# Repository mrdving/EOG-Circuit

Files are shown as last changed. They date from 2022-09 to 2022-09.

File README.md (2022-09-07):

# EOG-Circuit
An EOG circuit that gets the signal from the eye movement, and uses the output to control a game

EOG-TestDrive is the Unity Game. Created with Unity Engine version 2019.4.17f1
In the game, run Game scene and press space bar to begin, 'a' to move left, 'd' to move right

Keyboard_test.ino is the Script that runs in Arduino. Beware that only certain modules support the <Keyboard> package, such as Leonardo, but not Uno

CircuitDiagram Provides information on the components and connections

PCB contains KiCad file open with KiCad

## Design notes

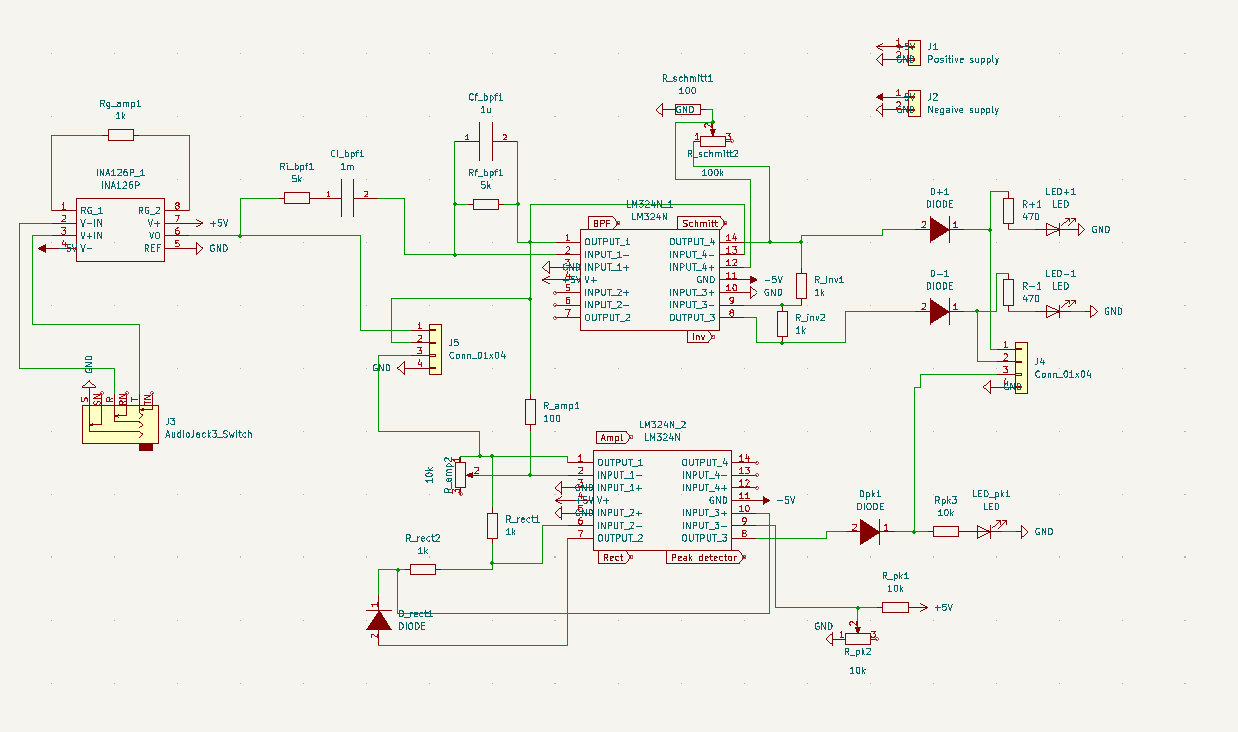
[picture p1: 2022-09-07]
CircuitDiagram.png

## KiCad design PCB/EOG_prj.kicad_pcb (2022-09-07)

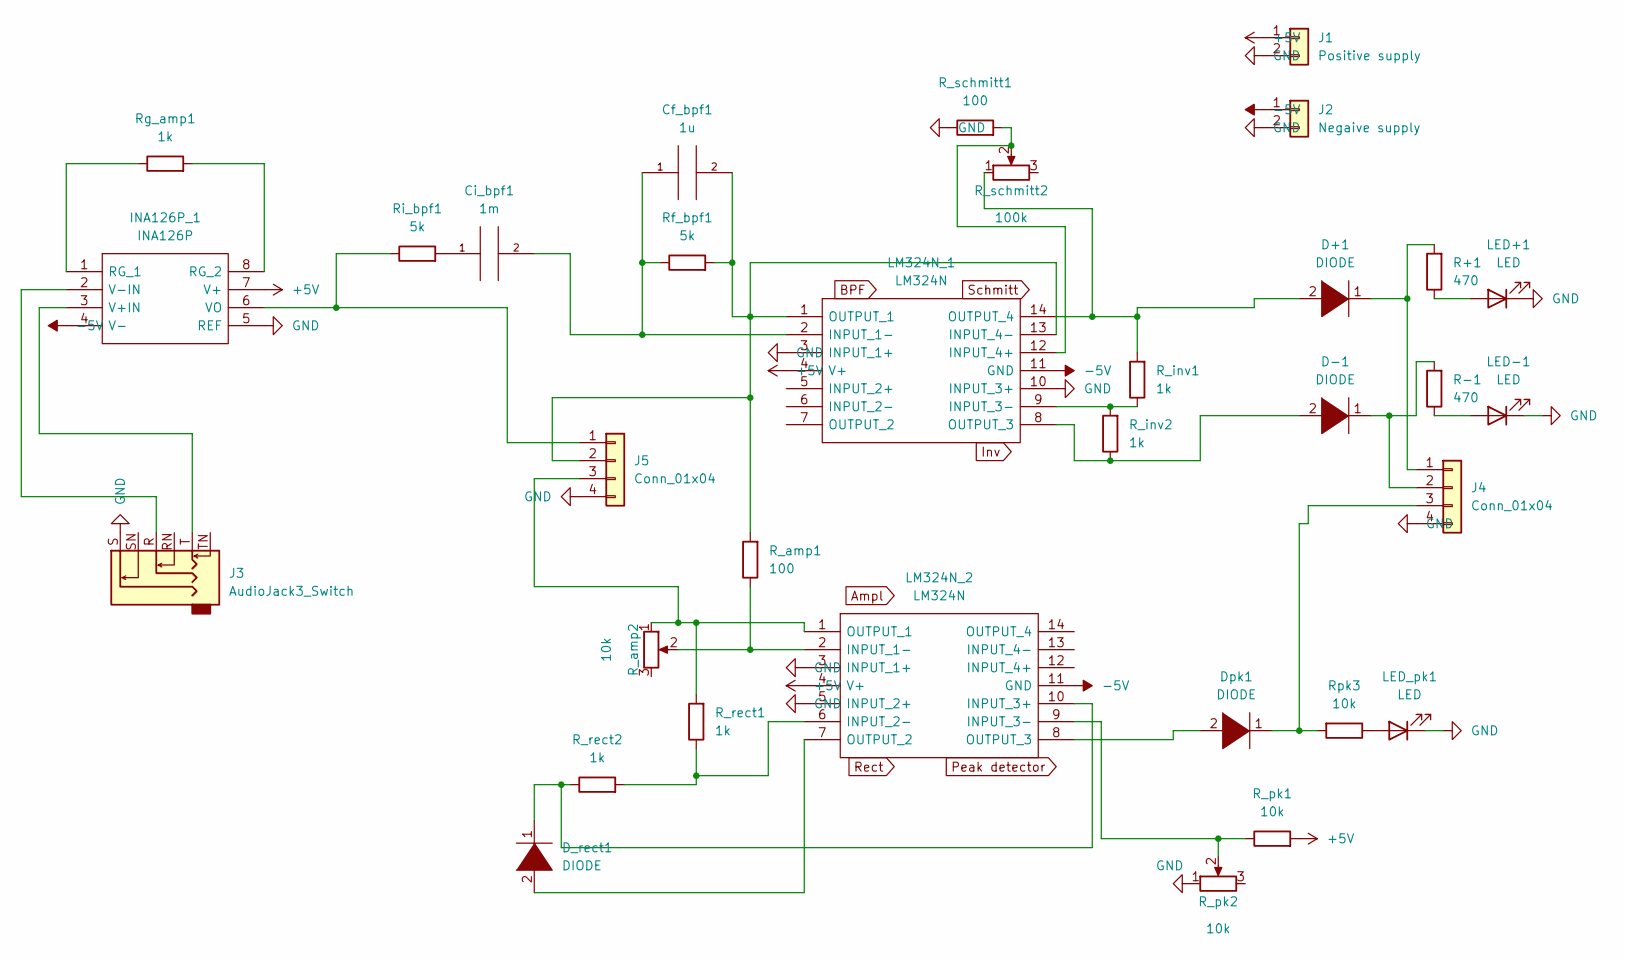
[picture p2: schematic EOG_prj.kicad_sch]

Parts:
Cf_bpf1: 1u; C_Radial_D5.0mm_H5.0mm_P2.00mm
Ci_bpf1: 1m; C_Radial_D12.5mm_H20.0mm_P5.00mm
D+1: DIODE; D_A-405_P10.16mm_Horizontal
D-1: DIODE; D_A-405_P10.16mm_Horizontal
D_rect1: DIODE; D_A-405_P10.16mm_Horizontal
Dpk1: DIODE; D_A-405_P10.16mm_Horizontal
INA126P_1: INA126P; DIP794W53P254L959H508Q8N; Manufacturer_Part_Number INA126P; Mouser Part Number 595-INA126P
J1: Positive supply; SolderWire-0.1sqmm_1x02_P3.6mm_D0.4mm_OD1mm
J2: Negaive supply; SolderWire-0.1sqmm_1x02_P3.6mm_D0.4mm_OD1mm
J3: AudioJack3_Switch; Jack_3.5mm_CUI_SJ1-3525N_Horizontal
J4, J5: Conn_01x04; SolderWire-0.1sqmm_1x04_P3.6mm_D0.4mm_OD1mm
LED+1: LED; LED_D3.0mm_Horizontal_O3.81mm_Z6.0mm
LED-1: LED; LED_D3.0mm_Horizontal_O3.81mm_Z6.0mm
LED_pk1: LED; LED_D3.0mm_Horizontal_O3.81mm_Z6.0mm
LM324N_1, LM324N_2: LM324N; DIP794W56P254L1905H533Q14N; Manufacturer_Part_Number LM324N; Mouser Part Number 595-LM324N
R+1: 470; R_Axial_DIN0207_L6.3mm_D2.5mm_P10.16mm_Horizontal
R-1: 470; R_Axial_DIN0207_L6.3mm_D2.5mm_P10.16mm_Horizontal
R_amp1: 100; R_Axial_DIN0207_L6.3mm_D2.5mm_P10.16mm_Horizontal
R_amp2: 10k; Potentiometer_Bourns_3339W_Horizontal
R_inv1, R_inv2: 1k; R_Axial_DIN0207_L6.3mm_D2.5mm_P10.16mm_Horizontal
R_pk1: 10k; R_Axial_DIN0207_L6.3mm_D2.5mm_P10.16mm_Horizontal
R_pk2: 10k; Potentiometer_Bourns_3339W_Horizontal
R_rect1, R_rect2: 1k; R_Axial_DIN0207_L6.3mm_D2.5mm_P10.16mm_Horizontal
R_schmitt1: 100; R_Axial_DIN0207_L6.3mm_D2.5mm_P10.16mm_Horizontal
R_schmitt2: 100k; Potentiometer_Bourns_3339W_Horizontal
Rf_bpf1: 5k; R_Axial_DIN0207_L6.3mm_D2.5mm_P10.16mm_Horizontal
Rg_amp1: 1k; R_Axial_DIN0207_L6.3mm_D2.5mm_P10.16mm_Horizontal
Ri_bpf1: 5k; R_Axial_DIN0207_L6.3mm_D2.5mm_P10.16mm_Horizontal
Rpk3: 10k; R_Axial_DIN0207_L6.3mm_D2.5mm_P10.16mm_Horizontal

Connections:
+5V: INA126P_1.7 (V+), J1.1, LM324N_1.4 (V+), LM324N_2.4 (V+), R_pk1.2
-5V: INA126P_1.4 (V-), J2.1, LM324N_1.11 (GND), LM324N_2.11 (GND)
GND: INA126P_1.5 (REF), J1.2, J2.2, J3.S, J4.4, J5.4, LED+1.1 (K), LED-1.1 (K), LED_pk1.1 (K), LM324N_1.3 (INPUT_1+), LM324N_1.10 (INPUT_3+), LM324N_2.3 (INPUT_1+), LM324N_2.5 (INPUT_2+), R_pk2.1, R_schmitt1.1
unnamed: Cf_bpf1.1, Ci_bpf1.2, LM324N_1.2 (INPUT_1-), Rf_bpf1.1
unnamed: Cf_bpf1.2, J5.2, LM324N_1.1 (OUTPUT_1), LM324N_1.13 (INPUT_4-), R_amp1.2, Rf_bpf1.2
unnamed: Ci_bpf1.1, Ri_bpf1.2
unnamed: INA126P_1.1 (RG_1), Rg_amp1.1
unnamed: INA126P_1.2 (V-IN), J3.R
unnamed: INA126P_1.3 (V+IN), J3.T
unnamed: INA126P_1.6 (VO), J5.1, Ri_bpf1.1
unnamed: INA126P_1.8 (RG_2), Rg_amp1.2
unnamed: D+1.1 (A), J4.1, R+1.2
unnamed: D-1.1 (A), J4.2, R-1.2
unnamed: Dpk1.1 (A), J4.3, Rpk3.2
unnamed: LED+1.2 (A), R+1.1
unnamed: LED-1.2 (A), R-1.1
unnamed: LED_pk1.2 (A), Rpk3.1
unnamed: D-1.2 (K), LM324N_1.8 (OUTPUT_3), R_inv2.1
unnamed: LM324N_1.9 (INPUT_3-), R_inv1.1, R_inv2.2
unnamed: LM324N_1.12 (INPUT_4+), R_schmitt1.2, R_schmitt2.2
unnamed: D+1.2 (K), LM324N_1.14 (OUTPUT_4), R_inv1.2, R_schmitt2.1
unnamed: J5.3, LM324N_2.1 (OUTPUT_1), R_amp2.1, R_rect1.2
unnamed: LM324N_2.2 (INPUT_1-), R_amp1.1, R_amp2.2
unnamed: LM324N_2.6 (INPUT_2-), R_rect1.1, R_rect2.2
unnamed: D_rect1.2 (K), LM324N_2.7 (OUTPUT_2)
unnamed: Dpk1.2 (K), LM324N_2.8 (OUTPUT_3)
unnamed: LM324N_2.9 (INPUT_3-), R_pk1.1, R_pk2.2
unnamed: D_rect1.1 (A), LM324N_2.10 (INPUT_3+), R_rect2.1

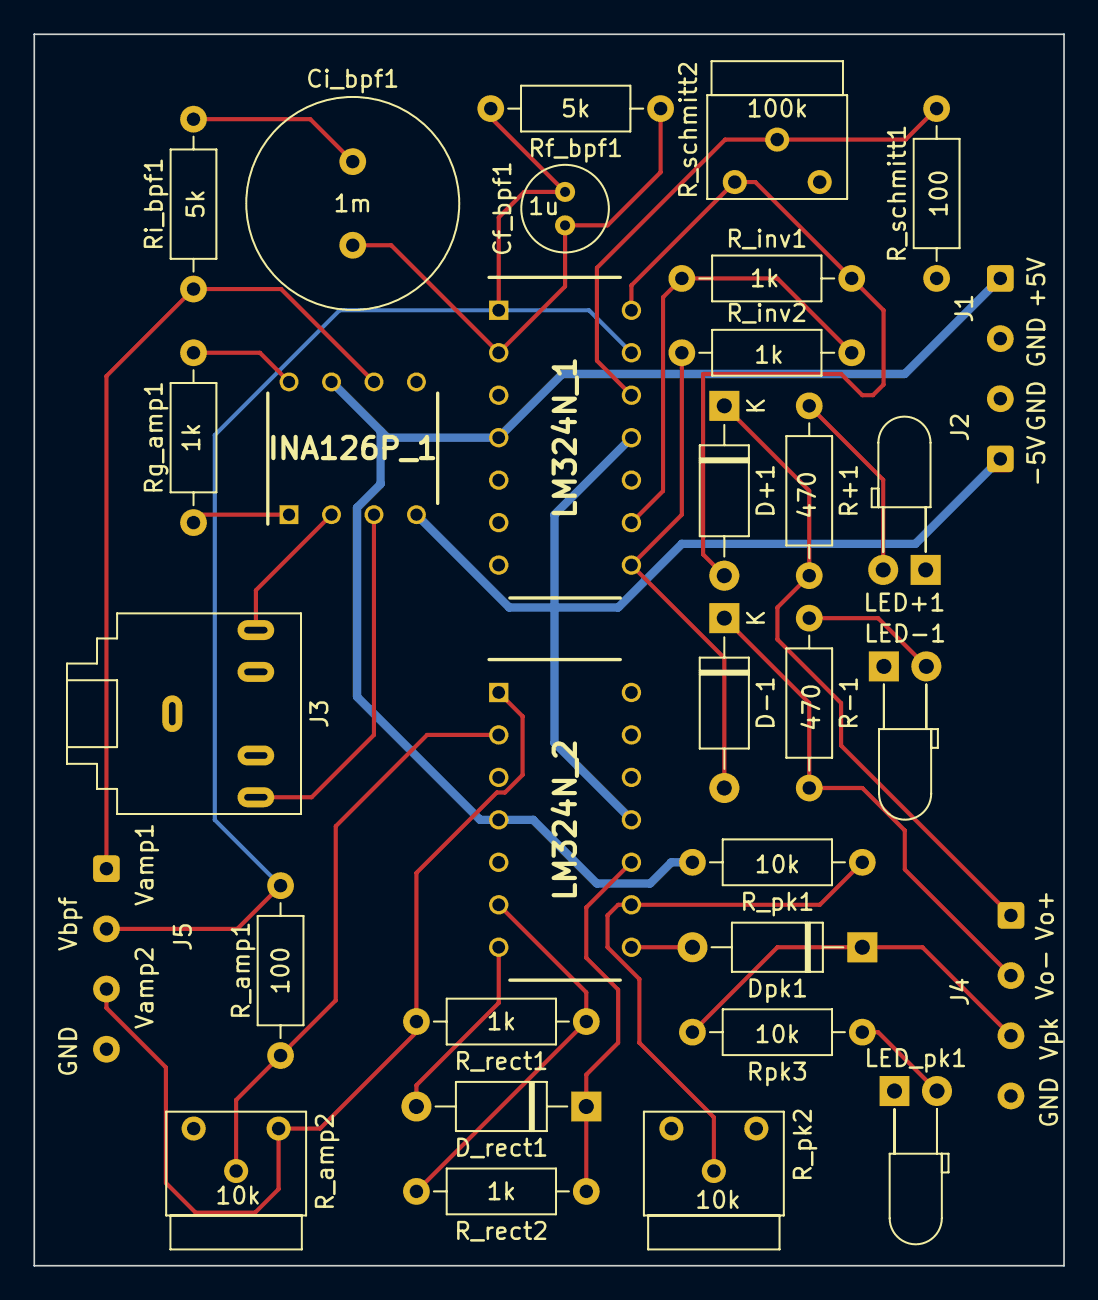
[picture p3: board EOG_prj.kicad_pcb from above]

Board: 2 copper layers, 61.6 x 73.7 mm, 33 parts (0 on the bottom side), 28 nets.

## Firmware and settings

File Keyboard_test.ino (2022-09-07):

#include<Keyboard.h>

const int pin_L = 2;
const int pin_R = 3;
const int pin_active = 4;
const int pin_Rect = A0;
const int pin_Schmitt = A5;
const int pin_BPF = A1;

const char key_L = 'a';
const char key_R = 'd';

void setup() {
  pinMode(pin_L, INPUT);
  pinMode(pin_R, INPUT);
  pinMode(pin_Rect, INPUT);
  pinMode(pin_Schmitt, INPUT);
  pinMode(pin_BPF, INPUT);
  
  
  Keyboard.begin();
  Serial.begin(9600);
}

void loop() {
  delay(100);
  Serial.print(digitalRead(pin_L)? 1 : 0);
  Serial.print(digitalRead(pin_active)? 1 : 0);
  Serial.print(digitalRead(pin_R)? 1 : 0);

  Serial.print(" BPF :");
  Serial.print(analogRead(pin_BPF));
  Serial.print(" Sch :");
  Serial.print(analogRead(pin_Schmitt));
  Serial.print(" Rec :");
  Serial.print(analogRead(pin_Rect));

  Serial.println("");

  
  //*
  if(digitalRead(pin_L) && digitalRead(pin_active))Keyboard.press(key_L);
  else Keyboard.release(key_L);
  
  if(digitalRead(pin_R) && digitalRead(pin_active))Keyboard.press(key_R);
  else Keyboard.release(key_R);
  //*/
}

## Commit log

2022-09-07 PCB
    PCB and schematics
    [EOG_prj.kicad_pcb, EOG_prj.kicad_sch]
2022-09-07 Circuit Diagram
2022-09-07 CircuitDiagram : Rename
2022-09-07 ArduinoControl upload
